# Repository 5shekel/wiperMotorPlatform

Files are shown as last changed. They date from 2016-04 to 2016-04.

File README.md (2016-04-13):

# wiperMotorPlatform
based on 2 wiper motors, NRF24 and a VNH2SP30 motor driver based arduino shield





##relay guides
http://www.learningaboutelectronics.com/Articles/DPDT-relay-wiring-diagram

http://www.me.umn.edu/courses/me2011/arduino/technotes/dcmotors/bidirectional/bidirMotor.html

  
[relay DPDT online simulation](http://lushprojects.com/circuitjs/circuitjs.html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)

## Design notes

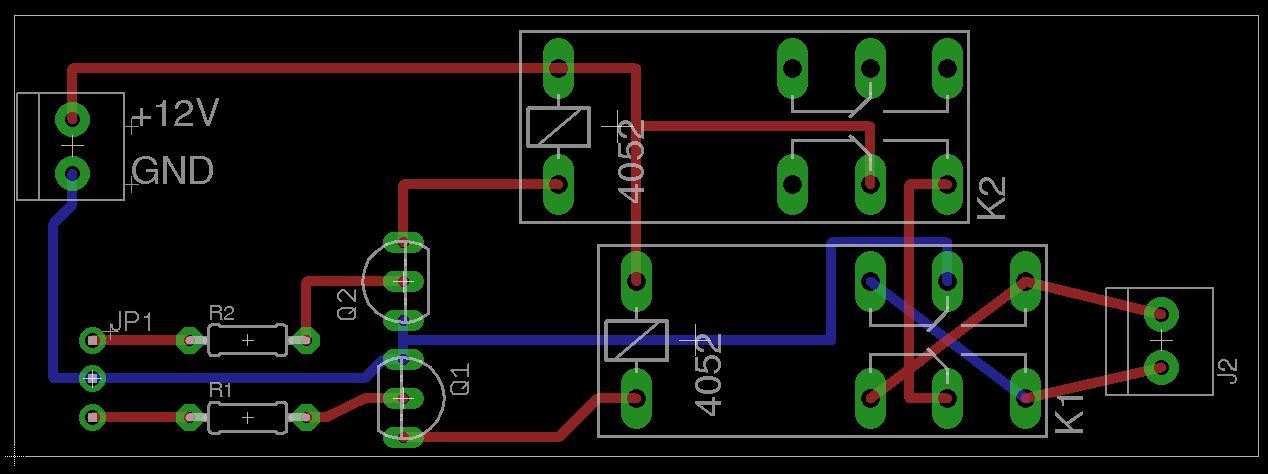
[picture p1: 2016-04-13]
circit.jpg

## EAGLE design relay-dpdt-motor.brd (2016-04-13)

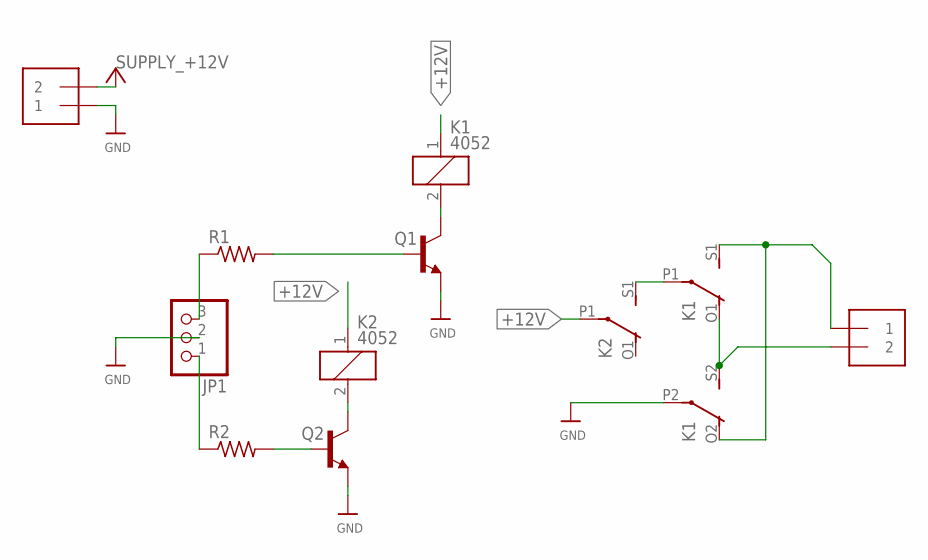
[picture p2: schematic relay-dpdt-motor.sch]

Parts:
J1, J2: 1X2-3.5MM
JP1: PINHD-1X3CB; 1X03-CLEANBIG
K1, K2: 4052; F4052
Q1, Q2: TRANSISTOR_BJT_NPN-TO-92-EBC; TO-92
R1, R2: R-US_0204/7; 0204/7

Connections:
+12V: J1.2, K1.1, K2.1, K2.P1
GND: J1.1, JP1.2, K1.P2, Q1.1 (E), Q2.1 (E)
unnamed: Q1.2 (B), R1.2
unnamed: K1.P1, K2.S1 (S)
unnamed: Q2.2 (B), R2.2
unnamed: K2.2, Q2.3 (C)
unnamed: JP1.1, R2.1
unnamed: J2.1, K1.O2 (O), K1.S1 (S)
unnamed: J2.2, K1.O1 (O), K1.S2 (S)
unnamed: K1.2, Q1.3 (C)
unnamed: JP1.3, R1.1

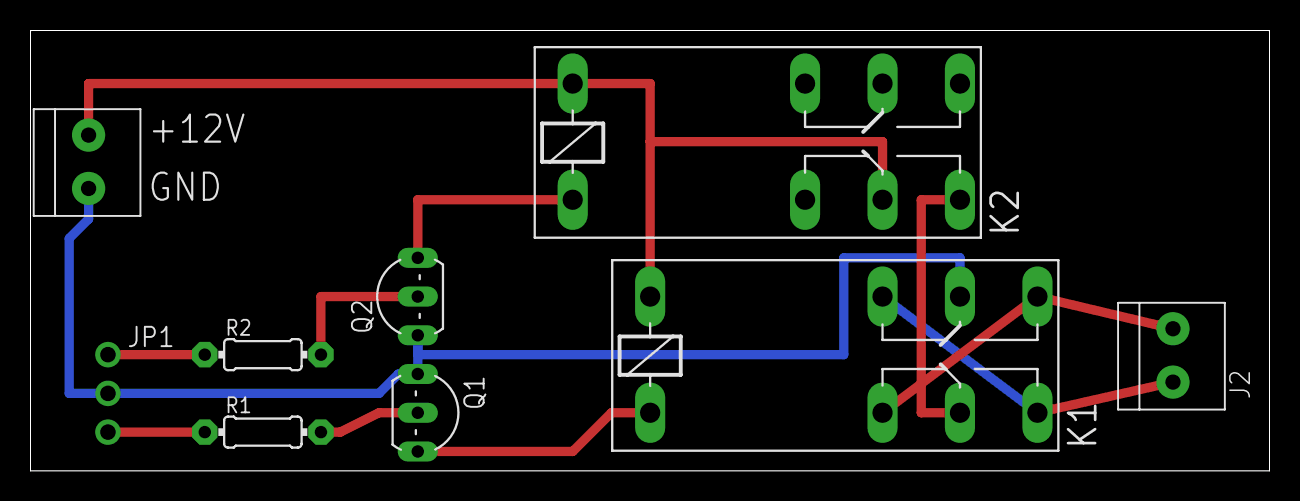
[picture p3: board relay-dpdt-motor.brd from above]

Board: 2 copper layers, 81.3 x 28.9 mm, 9 parts (0 on the bottom side), 11 nets.

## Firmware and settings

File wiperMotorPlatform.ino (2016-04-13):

#include "Streaming.h"
#include <SPI.h>
#include "RF24.h"

#define DEBUG 1

byte addresses[][7] = {"ampBot", "ampCtl"};

typedef enum { role_ping_out = 1, role_pong_back } role_e;                 // The various roles supported by this sketch
role_e role ;

/**
  Create a data structure for transmitting and receiving data
  This allows many variables to be easily sent and received in a single transmission
  See http://www.cplusplus.com/doc/tutorial/structures/
*/
struct dataStruct {
  unsigned long _micros;
  int xin;
  int yin;
} myData;


RF24 radio(9, 8); //also miso/mosi at 11/12/13
#define role_pin 2
///////  remote /////////////
#define AX_pin A0
#define AY_pin A1
///////// motor /////////////
int inApin[2] = {A3, 6};  // INA: Clockwise input
//had to change inBpin from the default  8,9
//beacuse of conflict with NRF24 wiring // on the nano side :/
int inBpin[2] = {7, 10}; // INB: Counter-clockwise input
int pwmpin[2] = {3, 5}; // PWM input

int x2pwm, y2pwm;
int leftMotorSpeed, rightMotorSpeed;

void setup() {
  Serial.begin(115200);
  radio.begin();

  pinMode(role_pin, INPUT);
  digitalWrite(role_pin, HIGH);
  delay(20); // Just to get a solid reading on the role pin
  // read the address pin, establish our role
  if ( digitalRead(role_pin) ) {
    role = role_pong_back;

    radio.openWritingPipe(addresses[1]);
    radio.openReadingPipe(1, addresses[0]);
    radio.startListening();

    if (DEBUG) Serial << "im a bot!" << endl;
  } else {
    role = role_ping_out;

    radio.openWritingPipe(addresses[0]);
    radio.openReadingPipe(1, addresses[1]);
    radio.stopListening();

    if (DEBUG) Serial << "im a controller!" << endl;
  }

  if (role == role_pong_back)
  {
    // Initialize motor pins as outputs
    for (int i = 0; i < 2; i++)
    {
      pinMode(inApin[i], OUTPUT);
      pinMode(inBpin[i], OUTPUT);
      pinMode(pwmpin[i], OUTPUT);
    }
    // Initialize braked
    for (int i = 0; i < 2; i++)
    {
      digitalWrite(inApin[i], LOW);
      digitalWrite(inBpin[i], LOW);
    }
  } else if (role == role_ping_out) {
    pinMode(AX_pin, INPUT);
    pinMode(AY_pin, INPUT);
  }
}


void loop() {
  /****************** Ping Out Role ***************************/

  if (role == role_ping_out)  {

    myData.xin = analogRead(AX_pin);
    if (myData.xin == 517) {
      myData.xin = 518; //terrible hack.
    }
    myData.yin = analogRead(AY_pin);

    bool ok = radio.write( &myData, sizeof(myData) );
    if (DEBUG) Serial << "xin:" << myData.xin << "  yin:" << myData.yin << endl;
    /*
      if (ok)
      Serial << "transfer OK  \n\r";
      else
      Serial << "transfer failed \n\r";
    */
  }



  /****************** Pong Back Role ***************************/

  else if ( role == role_pong_back )
  {

    if ( radio.available()) {
      // Variable for the received timestamp
      while (radio.available()) {                          // While there is data ready
        radio.read( &myData, sizeof(myData) );             // Get the payload
      }
      //process data
      x2pwm = map(myData.xin, 0, 1024, 255, -255);
      y2pwm = map(myData.yin, 0, 1024, 255, -255);

      leftMotorSpeed = constrain(y2pwm + x2pwm, -255, 255);
      rightMotorSpeed = constrain(y2pwm - x2pwm, -255, 255);

      move(1, rightMotorSpeed);
      move(0, leftMotorSpeed);

      if (myData.xin == 518 && myData.yin == 521) {
        stop(0);
        stop(1);
        if (DEBUG) Serial << "im down:" << endl;

      } else {
        if (DEBUG) Serial << "left:" << leftMotorSpeed << "  right:" << rightMotorSpeed << endl;
        if (DEBUG) Serial << "inY :" << myData.yin <<     "    inX:" << myData.xin << endl;
      }
      delay(4);
    }
  }


  delay(100); //pause comm, tweak!
} // Loop


// motor functions
void move(int motor, int speed) {
  if (speed < 0)
  {
    digitalWrite(inApin[motor], HIGH);
    digitalWrite(inBpin[motor], LOW);
  }
  else {
    digitalWrite(inApin[motor], LOW);
    digitalWrite(inBpin[motor], HIGH);
  }

  analogWrite(pwmpin[motor], abs(speed));
}


void stop(int motor) {
  digitalWrite(inApin[motor], LOW);
  digitalWrite(inBpin[motor], LOW);
  analogWrite(pwmpin[motor], 0);

}

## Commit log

2015-06-18 its working, but the motion is messy. probebly beacuse the oriontation of the joystick is wrong or somehting
    [wiperMotorPlatform.ino]
2016-04-12 relay version based on http://www.me.umn.edu/courses/me2011/arduino/technotes/dcmotors/bidirectional/bidirMotor.html
    [relay-dpdt-motor.sch]
2016-04-12 falstad.com circuit simualtor
2016-04-12 working sim, with MCU and flyback diode
2016-04-12 eagle prewired
    [relay-dpdt-motor.brd, relay-dpdt-motor.sch]
2016-04-12 brd update, wired
    [relay-dpdt-motor.brd]
2016-04-12 with pnp
    [relay-dpdt-motor.brd, relay-dpdt-motor.sch]
2016-04-12 2 relays one cup, including flyback
    [relay-dpdt-motor.brd, relay-dpdt-motor.sch]
2016-04-12 2 relays one cup, new sim
    [relay-dpdt-motor.brd, relay-dpdt-motor.sch]
2016-04-13 working relay, but i returned to using the monstermotor shield. and now with beter stop code for the motors
    [relay-dpdt-motor.brd, relay-dpdt-motor.sch]

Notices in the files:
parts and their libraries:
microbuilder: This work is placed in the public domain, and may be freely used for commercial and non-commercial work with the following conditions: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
